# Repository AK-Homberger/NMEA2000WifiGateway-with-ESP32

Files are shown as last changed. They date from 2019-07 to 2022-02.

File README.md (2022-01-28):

# NMEA2000 Wifi Gateway with ESP32
This repository shows how to build a NMEA2000 WiFi Gateway with AIS multiplexing and voltage/temperature alarms.
The ESP32 in this project is an ESP32 NODE MCU from AzDelivery. Pin layout for other ESP32 devices might differ.

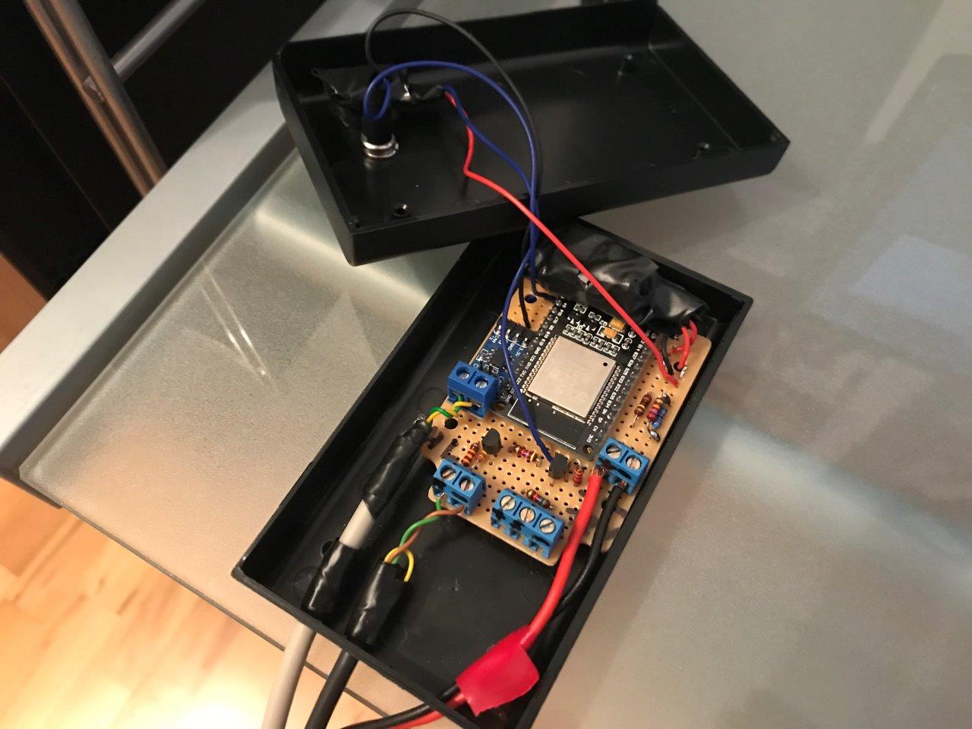
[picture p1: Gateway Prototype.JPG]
Prototype


The Gateway supports the following functions:

- Providing a WiFi Access Point for other systems like tablets or computer (e.g. with OpenCPN).
- Alternatively it can also connect as client to a WLAN network (set WLAN_CLIENT to 1 to enable).
- Forwarding navigation information from NMEA2000 to NMEA0183 as TCP stream (including log, water temp, and rudder information).
- Calculating TWS/TWD from apparent wind information and heading/COG). This allows use of OpenCPN WindHistory Dashbord instument.
- Forwarding serial NMEA0183 AIS information (on RX2) as UDP broadcast stream (for Navionics on tablets, but also for OpenCPN).
- Mutiplexing AIS information into TCP streams (to support applications that can handle only one (TCP) connection.
- Sending battery voltage and fridge temperature as NMEA2000 sentence (engine dynamic parameter PGN, my eS75 Ramarine MFD shows this as cooling temperature and alternator voltage).
- Battery voltage is measured with the ESP32 ADC.
- Fridge temperature with a Dallas DS18B20 OneWire sensor (easily extendable with more sensors).
- True parallel processing: Reading OneWire sensor as isolated task on second core of ESP32 (sensor reading is blocking for about 750 ms).
- Checking voltage and temperature levels against predefined values and generating an alarm with a piezo alarm buzzer.
- Acknowledgement of alarm with a button.
- Showing fridge temperature in web browser (nice JavaScript gauge).
- JSON interface on port 90 to request NMEA2000 data via JSON request (see M5Stack Display repository for example on usage).

The code is based on the NMEA 2000 / NMEA0183 libraries from Timo Lappalainen (https://github.com/ttlappalainen).
Download and install the libraries from GitHub link above:

- NMEA2000
- NMEA2000_esp32
- NMEA0183

The Gateway is using the following additional libraries (to be installed with the Arduiono IDE Library Manager):

- OneWire
- OneButton
- DallasTemperature
- ArduinoJson (Please use current version 6.x.x from now on)

For the ESP32 CAN bus, I used the "Waveshare SN65HVD230 Can Board" as transceiver. It works well with the ESP32.
For the Gateway, I use the pins GPIO4 for CAN RX and GPIO5 for CAN TX. The standard configuration of the NMEA2000 library would block the Serial2 connection used for AIS.

# !!!Caution!!! 
The former versions used Pin2 for TX. But I noticed problems with the NMEA2000 bus during reboot/programming of the ESP32. It looks like pin 2 is used during reboot and also during programming. A reboot confused the wind instrument (no TWS). With this new configuration evrything works without problems.

The 12 Volt is reduced to 5 Volt with a DC Step-Down_Converter (D24V10F5, https://www.pololu.com/product/2831).

The ADC of the ESP32 is a bit difficult to handle. You have to set the calibration information in the code according to the real values of the resistors at the ADC input of the ESP 32 (e.g. 15 for 100K / 27K which gives a range from 0 to 15 Volt).

# Configuration
To adjust the program to your need please change the following values in the code:

```
#define ENABLE_DEBUG_LOG 0 // Debug log, set to 1 to enable AIS forward on USB-Serial / 2 for ADC voltage to support calibration
#define UDP_Forwarding 0   // Set to 1 for forwarding AIS from serial2 to UDP brodcast
#define HighTempAlarm 12   // Alarm level for fridge temperature (higher)
#define LowVoltageAlarm 11 // Alarm level for battery voltage (lower)

#define ADC_Calibration_Value 34.3 // The real value depends on the true resistor values for the ADC input (100K / 27 K)

#define WLAN_CLIENT 0  // Set to 1 to enable client network. 0 to act as AP only

// Wifi cofiguration Client and Access Point
const char *AP_ssid = "MyESP32";  // ESP32 as AP
const char *CL_ssid = "MyWLAN";   // ESP32 as client in network

const char *AP_password = "appassword";   // AP password. Must be longer than 7 characters
const char *CL_password = "clientpassword";  // Client password

// Put IP address details here
IPAddress AP_local_ip(192, 168, 15, 1);  // Static address for AP
IPAddress AP_gateway(192, 168, 15, 1);
IPAddress AP_subnet(255, 255, 255, 0);

IPAddress CL_local_ip(192, 168, 1, 10);  // Static address for Client Network. Please adjust to your AP IP and DHCP range!
IPAddress CL_gateway(192, 168, 1, 1);
IPAddress CL_subnet(255, 255, 255, 0);
```

Schematics and PCB details are in the KiCAD folder (to allow modifications). The board can also be ordered at Aisler.net: https://aisler.net/p/DNXXRLFU

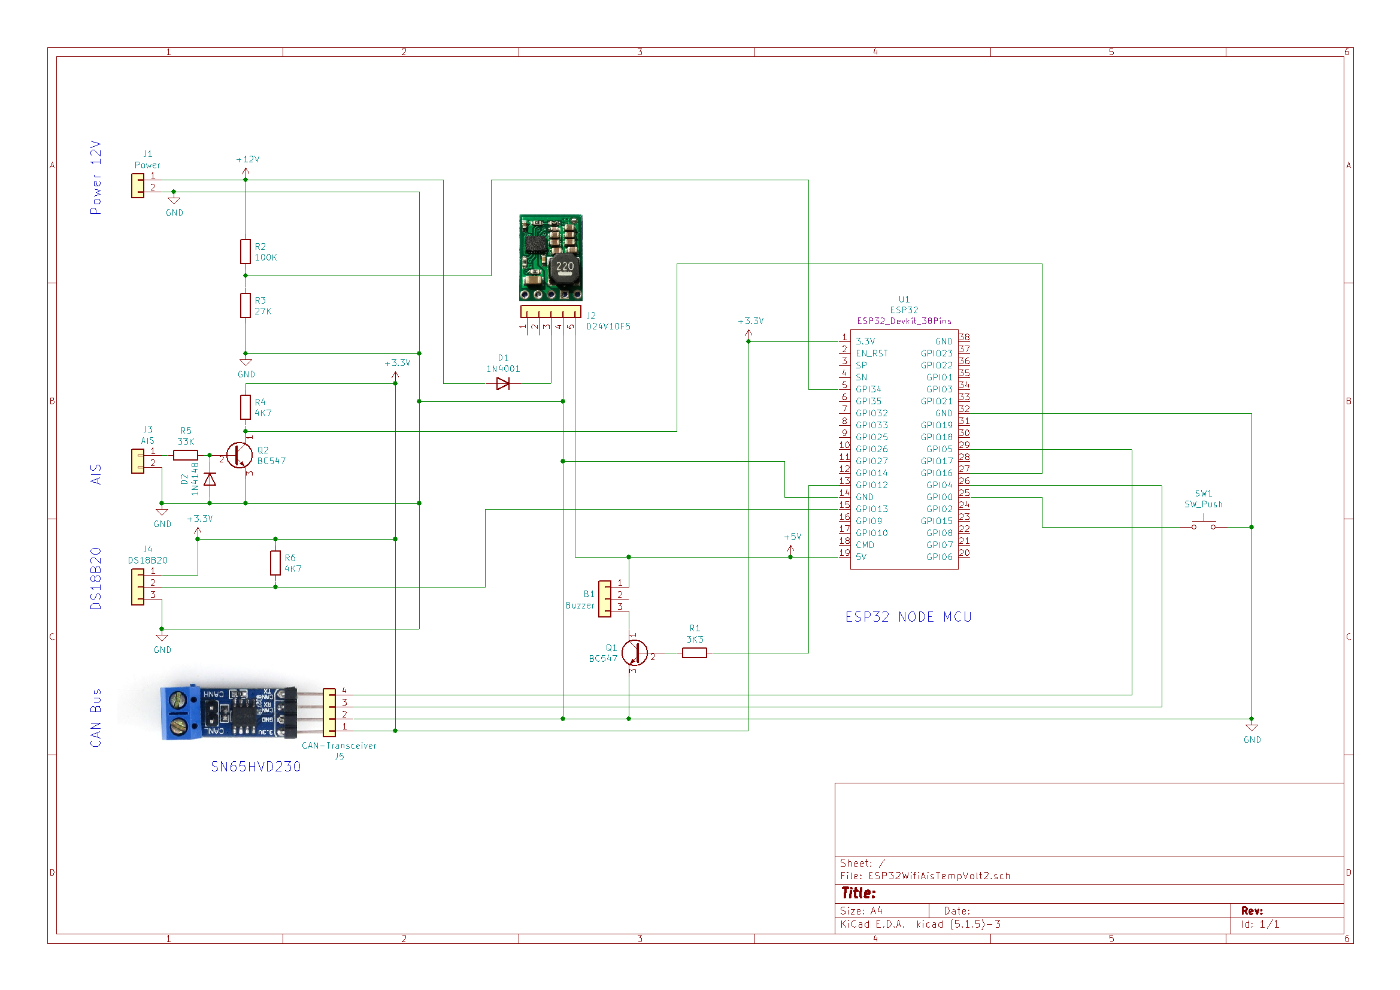
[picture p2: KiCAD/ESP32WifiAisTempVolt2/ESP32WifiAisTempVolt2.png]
Schematics


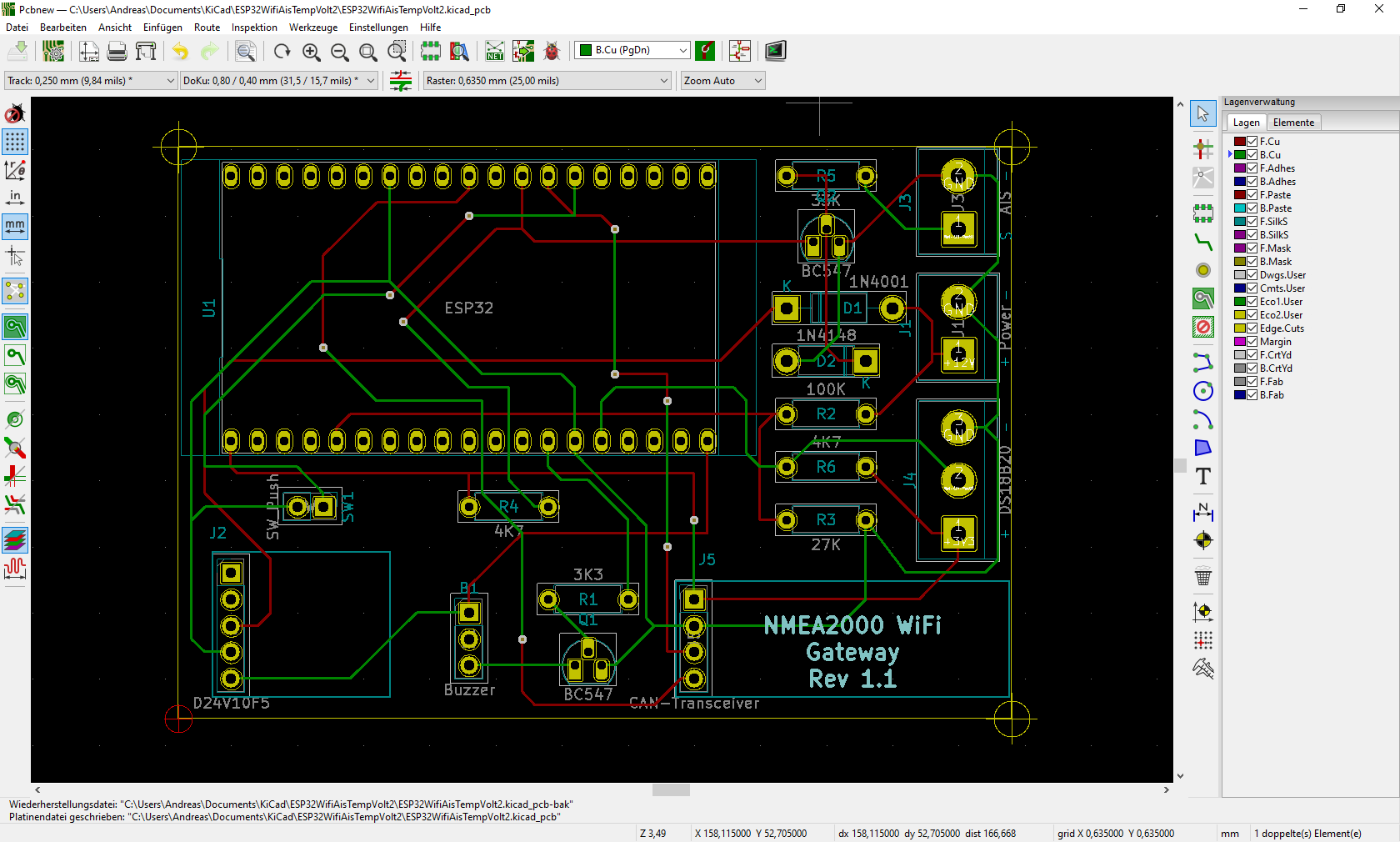
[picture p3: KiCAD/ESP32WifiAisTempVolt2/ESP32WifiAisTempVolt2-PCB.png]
PCB


# Be careful with placing the the ESP32 on the PCB. The USB connector has to be on the right side.

Fridge temperature is also shown with a nice web gauge:

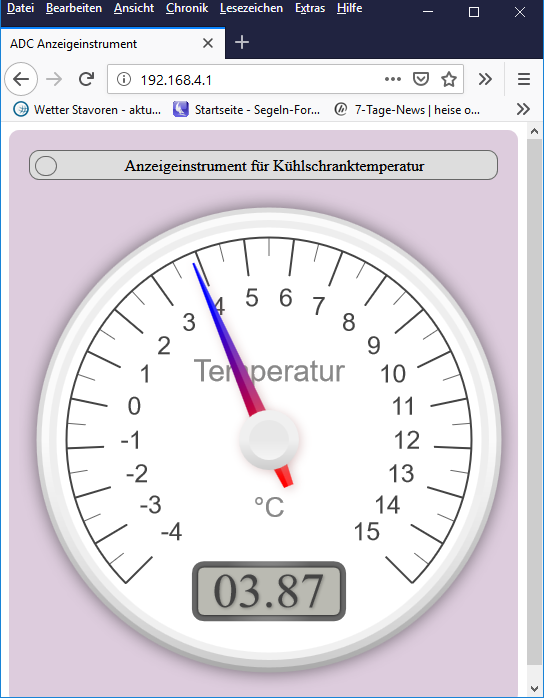
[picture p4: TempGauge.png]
TempGauge


# Remove the 120 ohm resistor from the transceiver
For unknown reasons, many CAN bus transceivers for the ESP32 have a 120 Ohm resistor built into them. The resistor does not belong to the devices at the ends of the stub lines, but to the ends of the backbone cable.

Whether the transceiver contains a 120 ohm resistor can be determined either by looking at the [circuit diagram](https://github.com/AK-Homberger/NMEA2000-Workshop/blob/main/Docs/SN65HVD230%20CAN%20Board_SCH.pdf) or by measuring with the multimeter.

A knife tip is suitable for removing the SMD resistor. Use it to scratch or pry off the resistance. With the transceiver shown here, place the tip of the knife in front of the resistor (between the chip and the resistor) and support the knife against the chip. Then lever the tip against the resistance and use it to scratch / loosen / break the resistance. Whichever happens first.

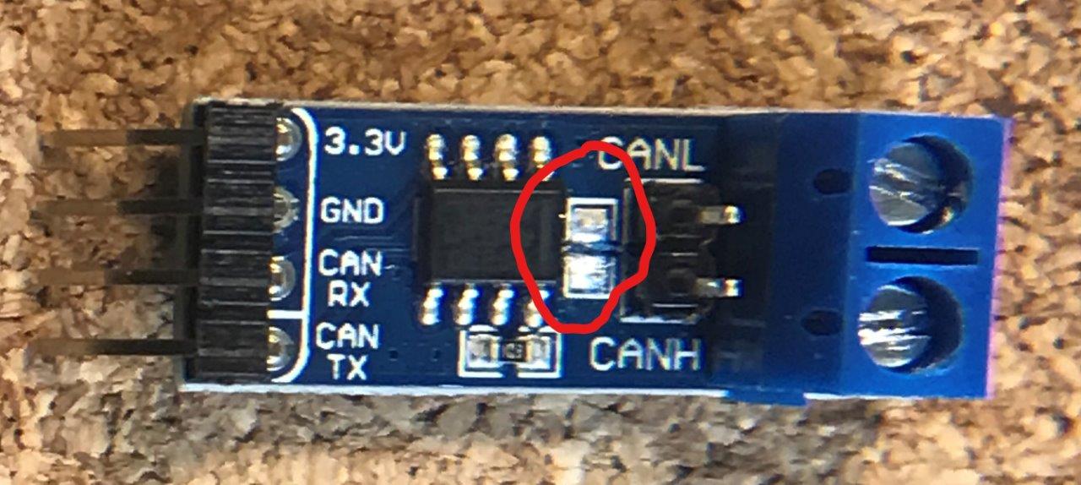
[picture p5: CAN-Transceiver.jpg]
Transceiver


It then looks like the picture. Then measure to be on the safe side. Without a 120 ohm resistor, the multimeter shows approx. 75 kOhm.

# Parts:

- Board [Link](https://aisler.net/p/DNXXRLFU)
- U1 ESP32 [Link](https://www.amazon.de/AZDelivery-NodeMCU-Development-Nachfolgermodell-ESP8266/dp/B071P98VTG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) 
- J5 SN65HVD230 [Link](https://eckstein-shop.de/WaveshareSN65HVD230CANTransceiverBoard33V2CESDProtection)
- J2 D24V10F5 [Link](https://eckstein-shop.de/Pololu5V2C1AStep-DownSpannungsreglerD24V10F5)
- B1 Buzzer [Link](https://www.reichelt.de/de/en/developer-boards-active-piezo-buzzer-module-debo-piezo-p239111.html?&nbc=1)
- R1 Resistor 3,3 KOhm [Link](https://www.reichelt.de/de/en/carbon-film-resistor-1-4-w-5-3-3-ohm-1-4w-3-3-p1396.html?&nbc=1)
- R2 Resistor 100 KOhm [Link](https://www.reichelt.de/de/en/carbon-film-resistor-1-4w-5-100-kilo-ohms-1-4w-100k-p1337.html?&nbc=1)
- R3 Resistor 27 KOhm [Link](https://www.reichelt.de/de/en/carbon-film-resistor-1-4-w-5-27-kohm-1-4w-27k-p1392.html?&nbc=1)
- R4, R6 Resistor 4,7 KOhm [Link](https://www.reichelt.de/de/en/carbon-film-resistor-1-4-w-5-4-7-kohm-1-4w-4-7k-p1425.html?&nbc=1)
- R5 Resistor 33 KOhm [Link](https://www.reichelt.de/de/en/carbon-film-resistor-1-4-w-5-33-kohm-1-4w-33k-p1412.html?&nbc=1)
- Q1, Q2 Transistor BC547 [Link](https://www.reichelt.de/de/en/small-signal-transistors-npn-to-92-45-v-rnd-bc547-p223356.html?&nbc=1)
- D1 Diode 1N4001 [Link](https://www.reichelt.com/de/en/rectifier-diode-do41-50-v-1-a-1n-4001-p1723.html?&nbc=1)
- D2 Diode 1N4148 [Link](https://www.reichelt.de/schalt-diode-100-v-150-ma-do-35-1n-4148-p1730.html?search=1n4148)
- SW1 Push button [Link](https://www.reichelt.de/miniatur-drucktaster-0-5a-24vac-1x-ein-rt-t-250a-rt-p31772.html?&trstct=pol_12&nbc=1)
- DS18B20 [Link](https://www.reichelt.com/shelly-temperatur-sensor-ds18b20-shelly-ds18b20-p287127.html?&trstct=pos_1&nbc=1)
- J4 Connector 3-pin [Link](https://www.reichelt.de/de/en/3-pin-terminal-strip-spacing-5-08-akl-101-03-p36606.html?&nbc=1)
- J1, J3 Connector 2-pin [Link](https://www.reichelt.de/de/en/2-pin-terminal-strip-spacing-5-08-akl-101-02-p36605.html?&nbc=1)
- Housing [Link](https://www.reichelt.de/de/en/plastic-housing-series-1591-57-x-87-x-36-mm-black-1591xxlsbk-p221267.html?&nbc=1)

# Updates:
- 06.11.20: Version 1.3: Changed PCB layout to version 1.1. Larger terminal blocks and different transistor footprints for easy soldering.
- 01.11.20: Version 1.3: Added KiCAD files.
- 04.08.20: Version 1.3: Changed CAN_TX to 5. Added WLAN client mode. Store last Node Address.
- 24.07.20: Version 1.2: Fixed AP setting problem (sometimes 192.168.4.1 was set after reboot).
- 23.07.20: Version 1.1: Moved to new JSON library version 6.x.x.
- 23.07.20: Version 1.0: Changed task 0 priority to 0 (see Issues) and corrected TWA calculation.
- 11.12.19: Version 0.9: Added CAN pin definition in code. No need to change settings in include file of library.
- 17.10.19: Version 0.8. Increase JSON buffer improved ID calculation.
- 14.10.19: Version 0.7. Added JSON interface on port 90. Added unique ID.
- 16.09.19: Added GGA sentence in N2kDataToNMEA0183.cpp
- 03.08.19: Version 0.4. Added rudder, log information. Calculate TWS/TWD from apparent wind, heading and COG. Added web gauge for fridge temperature (web browser, port 80).
- 23.07.19: Version 0.2 fixes the full AIS message forwarding issue. I'm now using the GetMessage function from the MNEA0183 library.

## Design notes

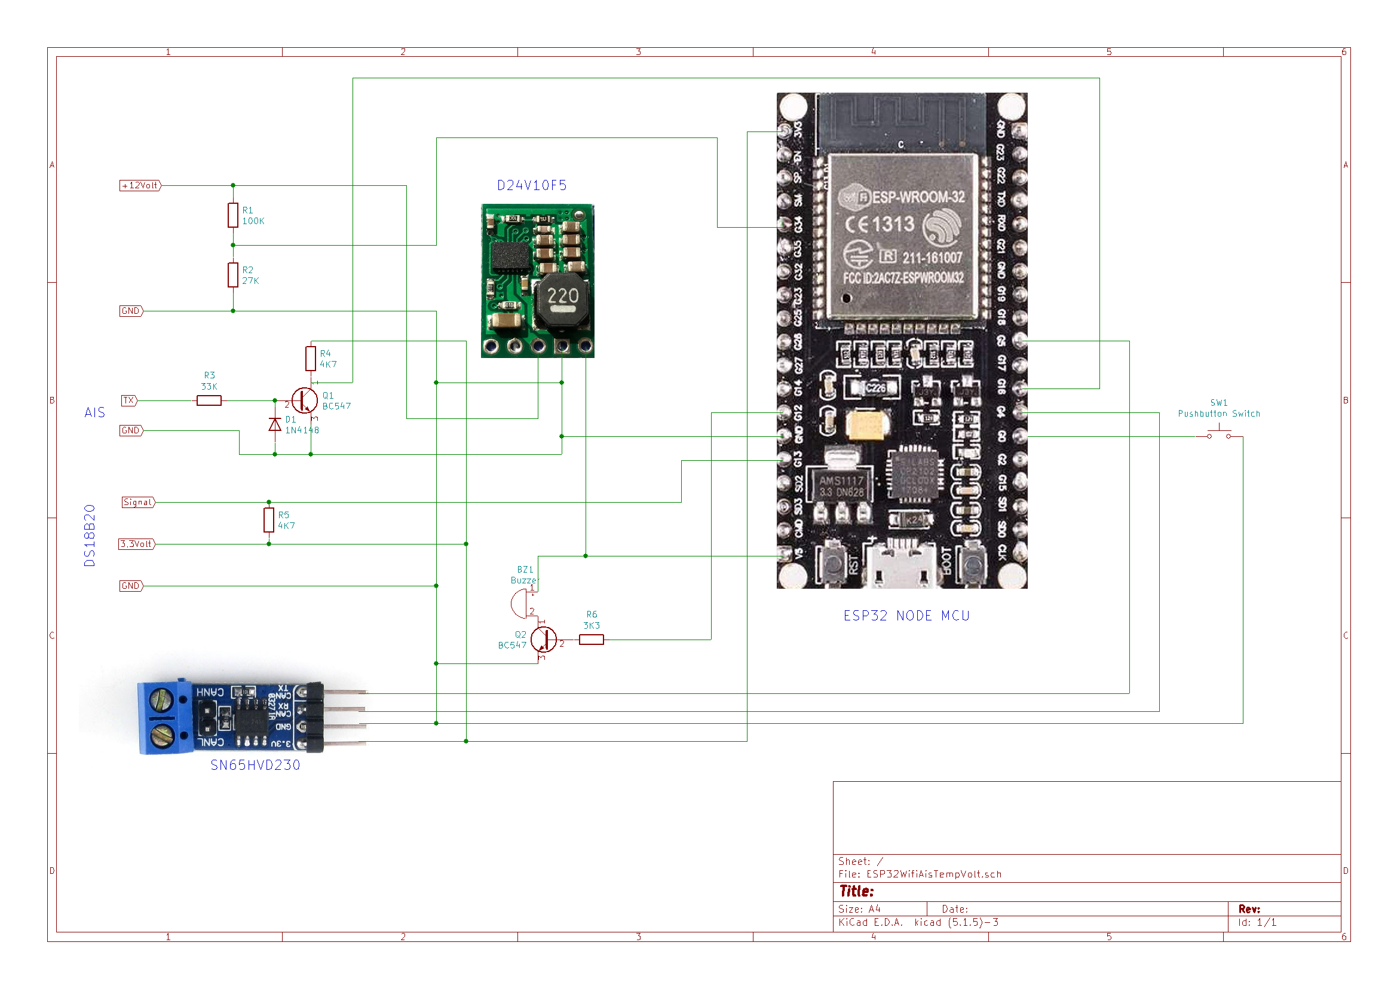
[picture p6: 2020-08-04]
NMEA 2000 WiFiGateway.png

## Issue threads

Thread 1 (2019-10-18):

ESP32_CAN Pins

ronzeiller, 2019-10-18:
Hi Andreas,
you are writing at https://github.com/ttlappalainen/NMEA2000/issues/97#issuecomment-513720750 that

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

But I could not find those pin definitions in your code?

Thanks,
Ronnie

AK-Homberger, 2019-10-31:
Hi Ronnie,

You are right. I changed the settinge in header file for the ESP 32 NMEA2000 library "NMEA2000_esp32.h":

#ifndef ESP32_CAN_TX_PIN
#define ESP32_CAN_TX_PIN GPIO_NUM_2
#endif
#ifndef ESP32_CAN_RX_PIN
#define ESP32_CAN_RX_PIN GPIO_NUM_4
#endif

It would be probably better to define it direcrtly in the main code to avoid confusion.

Regards,
Andreas

Closed 2019-12-11.

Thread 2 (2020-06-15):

Problems ArduinoJson

usauerbrey, 2020-06-15:
Hi
I have problems when trying to compile you NMEA-Gateway.

Wifi-Serial-AP-AIS-CAN.ino: 413:11: error: StaticJsonBuffer is a class from ArduinoJson 5. Please see arduinojson.org\upgrade to learn how to upgrade your program to ArduinoJson version 6
   StaticJsonBuffer<800> jsonBuffer

Any solution/recommendation?

Best Regards Uwe

AndrasSzep, 2020-06-15:
Hi Uwe,

Actually I only forked the library from
AK-Homberger/NMEA2000WifiGateway-with-ESP32 and used only to develop
my own apps.
If you describe what you want perhaps I can give you some hints.

Kind regards,

------------------
András Szép
andras.szep@gmail.com
UK: +44 - 7824 35 9474

------------------
András Szép
andras.szep@gmail.com
UK: +44 - 7824 35 9474

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

AK-Homberger, 2020-06-15:
Did you install the JSON library version 5?

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

AndrasSzep, 2020-06-15:
I have ArduinoJSON 6.15.2 installed on my comp, but not sure if I ever used
It yet.
I have an app publishing NMEA2000 messages in NMEA0183 format as a TCP
stream. This can be used by OpenCPN.
Also just made the other way around - translating NMEA0183 messages from a
TCP stream into NMEA2000 bus.

------------------
András Szép
andras.szep@gmail.com
UK: +44 - 7824 35 9474

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

usauerbrey, 2020-06-15:
I was able to install ArduinoJSON 5 instead of ArduinoJSON 6. I was not aware, that this is posslible.
So now it woks, even so it is not perfect, not using the latest libriries.

AK-Homberger, 2020-06-15:
You have to use JSON version 5 not 6. Then it should work.

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

AK-Homberger, 2020-07-24:
Now the code works with ArduinoJSON verion 6.

Closed 2020-06-16.

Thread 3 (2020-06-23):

Compiling on PlatformIO

AAKFISHERMANN, 2020-06-23:
HI, i tried to compile this code on Atom PlatformIO. Using different espressif32 platform versions (1.7.0, 1.8.0 and the last 1.12.4) i have the same error at the end of compiling;

Linking .pio\build\esp32doit-devkit-v1\firmware.elf
.pio\build\esp32doit-devkit-v1\src\main.cpp.o:(.literal.startup._GLOBAL__sub_I_NMEA2000+0x10): **undefined reference to `vtable for tN2kDataToNMEA0183'**
.pio\build\esp32doit-devkit-v1\src\main.cpp.o:(.literal._Z4loopv+0x4): **undefined reference to `tN2kDataToNMEA0183::Update(tBoatData*)'**
.pio\build\esp32doit-devkit-v1\src\main.cpp.o: In function `loop()':
main.cpp:(.text._Z4loopv+0x39): **undefined reference to `tN2kDataToNMEA0183::Update(tBoatData*)'**
collect2.exe: error: ld returned 1 exit status
*** [.pio\build\esp32doit-devkit-v1\firmware.elf] Error 1

Is there some kind a problem in one library?
Thanks

AK-Homberger, 2020-06-23:
Hi,
I don’t use this environment. Regarding problems with the libraries you should check this with the author of the libraries, Timo Lappalainen.

Regards
Andreas

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

AndrasSzep, 2020-06-23:
Sometimes it is quite funny the behavior of the different ESP32 chips.
Errors when loading the programs maybe caused by too much current load or
too long USB cables. Some chips need lower loading speeds and or pushing
the boot button...

On Tue, 23 Jun 2020 at 19:57, AAKFISHERMANN <notifications@github.com>
wrote:

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
--
András

AK-Homberger, 2020-07-23:
PlatformIO is not supported.

Closed 2020-07-23.

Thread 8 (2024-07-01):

infinite loop when wifi client disconnects

florent1080, 2024-07-01:
When a wifi client is disconnected, the SendBufToClients() timeout is too long and the code loops infinitely in HandleNMEA2000Msg(), because messages are arriving on the Can bus. I don't have a fix yet, but I'm working on it.

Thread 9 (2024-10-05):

NMEA2000_esp does not compile.

dfs-brent, 2024-10-05:
I had to comment out the following lines from the NMEA2000_esp.cpp to get it to compile:
        Line 124:   ///periph_module_reset(PERIPH_CAN_MODULE);
	Line 128:   ///DPORT_SET_PERI_REG_MASK(DPORT_PERIP_CLK_EN_REG, DPORT_CAN_CLK_EN);
	Line 129:   ///DPORT_CLEAR_PERI_REG_MASK(DPORT_PERIP_RST_EN_REG, DPORT_CAN_RST);
	Line 194:     ///esp_intr_alloc(ETS_CAN_INTR_SOURCE,0,ESP32Can1Interrupt,NULL,NULL);

It does not know what the *_CAN_* macros are.  Obviously, it will not work without these lines.  Any idea how to fix this properly?

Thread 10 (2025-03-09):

ESP32_ DS18B20

Machansen, 2025-03-09:
Hello,

I would like to read the DS18B20. Unfortunately, the sensors don't seem to be recognized. The signal is connected to pin 13 and tested. Do the sensors need to be installed separately? They are also not shown under 'Show Unmapped'.

Thank you for your help!

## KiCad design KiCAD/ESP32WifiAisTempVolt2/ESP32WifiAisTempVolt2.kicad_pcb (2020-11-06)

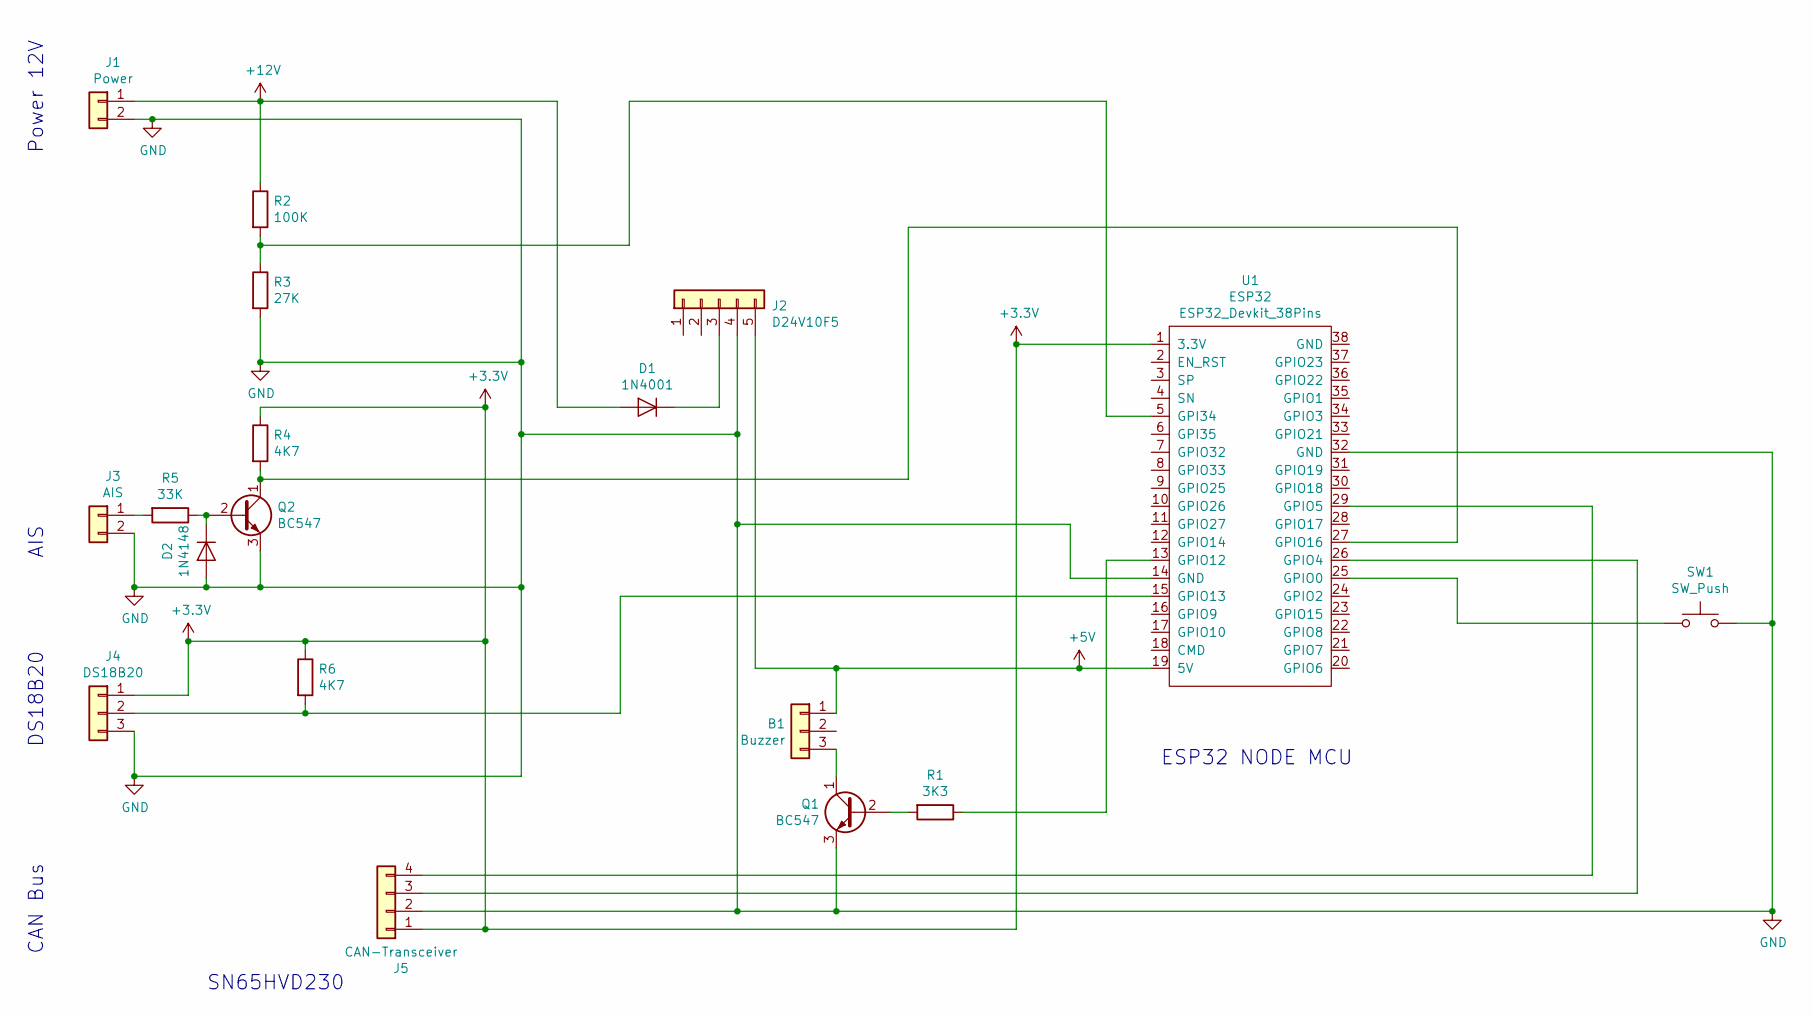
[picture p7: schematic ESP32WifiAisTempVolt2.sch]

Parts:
B1: Buzzer; PinHeader_1x03_P2.54mm_Vertical
D1: 1N4001; D_DO-41_SOD81_P10.16mm_Horizontal
D2: 1N4148; D_DO-41_SOD81_P7.62mm_Horizontal
J1: Power; TerminalBlock_bornier-2_P5.08mm
J2: D24V10F5; PinHeader_1x05_P2.54mm_Vertical
J3: AIS; TerminalBlock_bornier-2_P5.08mm
J4: DS18B20; TerminalBlock_bornier-3_P5.08mm
J5: CAN-Transceiver; PinHeader_1x04_P2.54mm_Vertical
Q1, Q2: BC547; TO-92_HandSolder
R1: 3K3; R_Axial_DIN0207_L6.3mm_D2.5mm_P7.62mm_Horizontal
R2: 100K; R_Axial_DIN0207_L6.3mm_D2.5mm_P7.62mm_Horizontal
R3: 27K; R_Axial_DIN0207_L6.3mm_D2.5mm_P7.62mm_Horizontal
R4, R6: 4K7; R_Axial_DIN0207_L6.3mm_D2.5mm_P7.62mm_Horizontal
R5: 33K; R_Axial_DIN0207_L6.3mm_D2.5mm_P7.62mm_Horizontal
SW1: SW_Push; PinHeader_1x02_P2.54mm_Vertical
U1: ESP32; ESP32_Devkit_38Pins

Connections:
+3V3: J4.1, J5.1, R4.1, R6.1, U1.1 (3.3V)
+5V: B1.1, J2.5, U1.19 (5V)
+12V: D1.2 (A), J1.1, R2.1
GND: D2.2 (A), J1.2, J2.4, J3.2, J4.3, J5.2, Q1.3 (E), Q2.3 (E), R3.2, SW1.2, U1.14 (GND), U1.32 (GND)
unnamed: B1.3, Q1.1 (C)
unnamed: D1.1 (K), J2.3
unnamed: D2.1 (K), Q2.2 (B), R5.1
unnamed: J3.1, R5.2
unnamed: J4.2, R6.2, U1.15 (GPIO13)
unnamed: J5.3, U1.26 (GPIO4)
unnamed: J5.4, U1.29 (GPIO5)
unnamed: Q1.2 (B), R1.2
unnamed: Q2.1 (C), R4.2, U1.27 (GPIO16)
unnamed: R1.1, U1.13 (GPIO12)
unnamed: R2.2, R3.1, U1.5 (GPI34)
unnamed: SW1.1, U1.25 (GPIO0)

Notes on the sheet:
ESP32 NODE MCU
SN65HVD230
CAN Bus
Power 12V
DS18B20
AIS

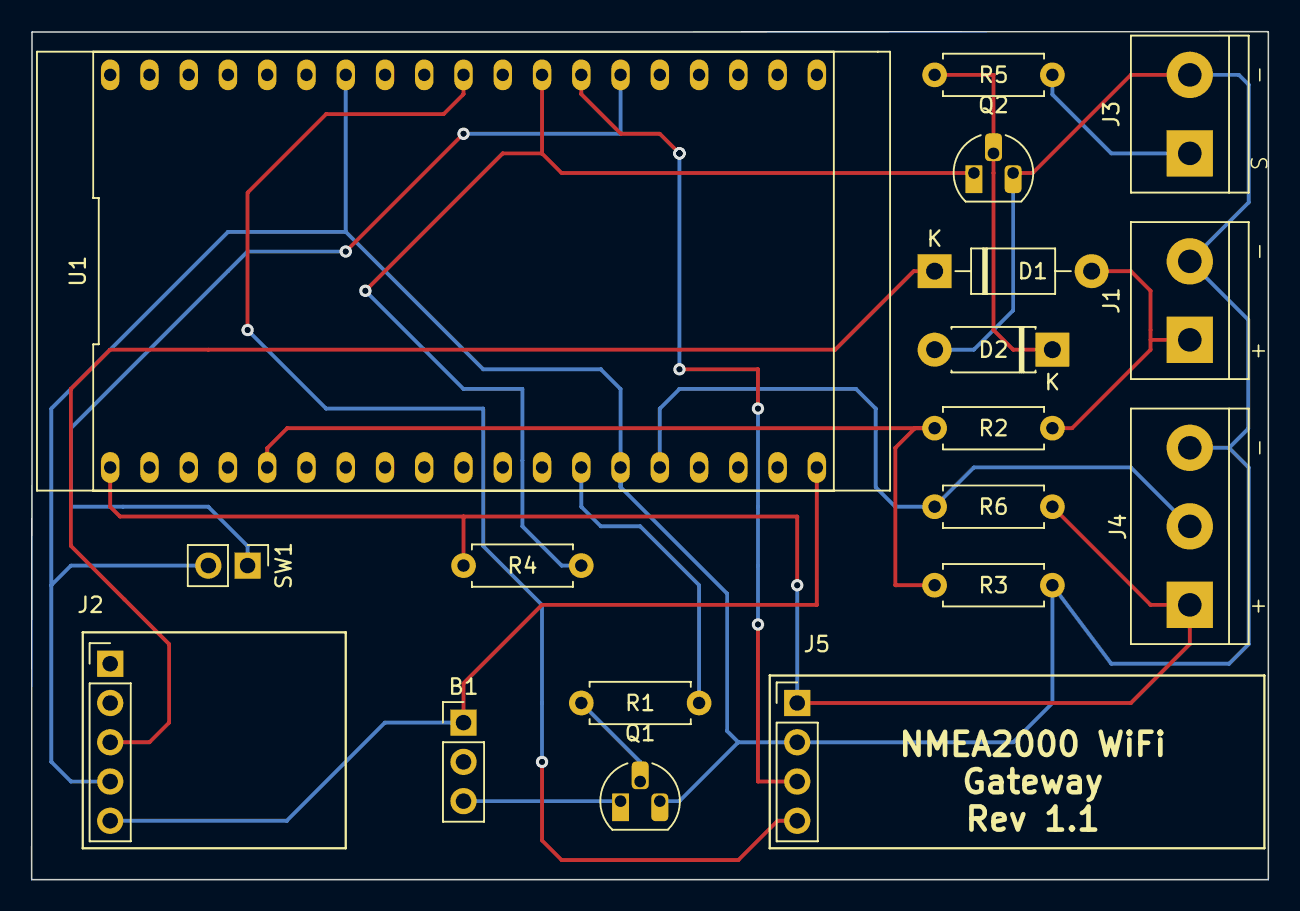
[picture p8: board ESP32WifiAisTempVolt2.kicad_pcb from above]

Board: 2 copper layers, 80.0 x 54.9 mm, 18 parts (0 on the bottom side), 16 nets.

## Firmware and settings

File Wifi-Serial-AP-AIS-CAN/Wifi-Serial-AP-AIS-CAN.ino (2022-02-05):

/*
  This code is free software; you can redistribute it and/or
  modify it under the terms of the GNU Lesser General Public
  License as published by the Free Software Foundation; either
  version 2.1 of the License, or (at your option) any later version.
  This code is distributed in the hope that it will be useful,
  but WITHOUT ANY WARRANTY; without even the implied warranty of
  MERCHANTABILITY or FITNESS FOR A PARTICULAR PURPOSE.  See the GNU
  Lesser General Public License for more details.
  You should have received a copy of the GNU Lesser General Public
  License along with this library; if not, write to the Free Software
  Foundation, Inc., 51 Franklin St, Fifth Floor, Boston, MA  02110-1301  USA
*/

// Version 1.3, 04.08.2020, AK-Homberger

#define ESP32_CAN_TX_PIN GPIO_NUM_5  // Set CAN TX port to 5 (Caution!!! Pin 2 before)
#define ESP32_CAN_RX_PIN GPIO_NUM_4  // Set CAN RX port to 4

#include <Arduino.h>
#include <NMEA2000_CAN.h>  // This will automatically choose right CAN library and create suitable NMEA2000 object
#include <Seasmart.h>
#include <N2kMessages.h>
#include <WiFi.h>
#include <WebServer.h>
#include <OneWire.h>
#include <OneButton.h>
#include <DallasTemperature.h>
#include <Preferences.h>
#include <ArduinoJson.h>

#include "N2kDataToNMEA0183.h"
#include "List.h"
#include "index_html.h"
#include "BoatData.h"


#define ENABLE_DEBUG_LOG 0 // Debug log, set to 1 to enable AIS forward on USB-Serial / 2 for ADC voltage to support calibration
#define UDP_Forwarding 0   // Set to 1 for forwarding AIS from serial2 to UDP brodcast
#define HighTempAlarm 12   // Alarm level for fridge temperature (higher)
#define LowVoltageAlarm 11 // Alarm level for battery voltage (lower)

#define ADC_Calibration_Value 34.3 // The real value depends on the true resistor values for the ADC input (100K / 27 K)

#define WLAN_CLIENT 0  // Set to 1 to enable client network. 0 to act as AP only

// Wifi cofiguration Client and Access Point
const char *AP_ssid = "MyESP32";  // ESP32 as AP
const char *CL_ssid = "MyWLAN";   // ESP32 as client in network

const char *AP_password = "appassword";   // AP password. Must be longer than 7 characters
const char *CL_password = "clientpassword";  // Client password

// Put IP address details here
IPAddress AP_local_ip(192, 168, 15, 1);  // Static address for AP
IPAddress AP_gateway(192, 168, 15, 1);
IPAddress AP_subnet(255, 255, 255, 0);

IPAddress CL_local_ip(192, 168, 1, 10);  // Static address for Client Network. Please adjust to your AP IP and DHCP range!
IPAddress CL_gateway(192, 168, 1, 1);
IPAddress CL_subnet(255, 255, 255, 0);

int wifiType = 0; // 0= Client 1= AP

const uint16_t ServerPort = 2222; // Define the port, where server sends data. Use this e.g. on OpenCPN. Use 39150 for Navionis AIS

// UPD broadcast for Navionics, OpenCPN, etc.
const char * udpAddress = "192.168.15.255"; // UDP broadcast address. Should be the network of the ESP32 AP (please check!)
const int udpPort = 2000; // port 2000 lets think Navionics it is an DY WLN10 device

// Create UDP instance
WiFiUDP udp;

// Struct to update BoatData. See BoatData.h for content
tBoatData BoatData;

int NodeAddress;  // To store last Node Address

Preferences preferences;             // Nonvolatile storage on ESP32 - To store LastDeviceAddress

int buzzerPin = 12;   // Buzzer on GPIO 12
int buttonPin = 0;    // Button on GPIO 0 to acknowledge alarm with buzzer
int alarmstate = false; // Alarm state (low voltage/temperature)
int acknowledge = false; // Acknowledge for alarm, button pressed

OneButton button(buttonPin, false); // The OneButton library is used to debounce the acknowledge button

const size_t MaxClients = 10;
bool SendNMEA0183Conversion = true; // Do we send NMEA2000 -> NMEA0183 conversion
bool SendSeaSmart = false; // Do we send NMEA2000 messages in SeaSmart format

WiFiServer server(ServerPort, MaxClients);
WiFiServer json(90);

using tWiFiClientPtr = std::shared_ptr<WiFiClient>;
LinkedList<tWiFiClientPtr> clients;

tN2kDataToNMEA0183 tN2kDataToNMEA0183(&NMEA2000, 0);

// Set the information for other bus devices, which messages we support
const unsigned long TransmitMessages[] PROGMEM = {127489L, // Engine dynamic
                                                  0
                                                 };
const unsigned long ReceiveMessages[] PROGMEM = {/*126992L,*/ // System time
      127250L, // Heading
      127258L, // Magnetic variation
      128259UL,// Boat speed
      128267UL,// Depth
      129025UL,// Position
      129026L, // COG and SOG
      129029L, // GNSS
      130306L, // Wind
      128275UL,// Log
      127245UL,// Rudder
      0
    };

// Forward declarations
void HandleNMEA2000Msg(const tN2kMsg &N2kMsg);
void SendNMEA0183Message(const tNMEA0183Msg &NMEA0183Msg);

// Data wire for teperature (Dallas DS18B20) is plugged into GPIO 13 on the ESP32
#define ONE_WIRE_BUS 13
// Setup a oneWire instance to communicate with any OneWire devices (not just Maxim/Dallas temperature ICs)
OneWire oneWire(ONE_WIRE_BUS);
// Pass our oneWire reference to Dallas Temperature.
DallasTemperature sensors(&oneWire);

WebServer webserver(80);

#define MiscSendOffset 120
#define SlowDataUpdatePeriod 1000  // Time between CAN Messages sent

// Battery voltage is connected GPIO 34 (Analog ADC1_CH6)
const int ADCpin = 34;
float voltage = 0;
float temp = 0;

// Task handle for OneWire read (Core 0 on ESP32)
TaskHandle_t Task1;

// Serial port 2 config (GPIO 16)
const int baudrate = 38400;
const int rs_config = SERIAL_8N1;

// Buffer config

#define MAX_NMEA0183_MESSAGE_SIZE 150 // For AIS
char buff[MAX_NMEA0183_MESSAGE_SIZE];

// NMEA message for AIS receiving and multiplexing
tNMEA0183Msg NMEA0183Msg;
tNMEA0183 NMEA0183;


void debug_log(char* str) {
#if ENABLE_DEBUG_LOG == 1
  Serial.println(str);
#endif
}



void setup() {

  uint8_t chipid[6];
  uint32_t id = 0;
  int i = 0;
  int wifi_retry = 0;

  pinMode(buzzerPin, OUTPUT);
  pinMode(buttonPin, INPUT_PULLUP);

  button.attachClick(clickedIt);

  // Init USB serial port
  Serial.begin(115200);

  // Init AIS serial port 2
  Serial2.begin(baudrate, rs_config);
  NMEA0183.Begin(&Serial2, 3, baudrate);

  if (WLAN_CLIENT == 1) {
    Serial.println("Start WLAN Client");         // WiFi Mode Client

    WiFi.config(CL_local_ip, CL_gateway, CL_subnet, CL_gateway);
    delay(100);
    WiFi.begin(CL_ssid, CL_password);

    while (WiFi.status() != WL_CONNECTED  && wifi_retry < 20) {         // Check connection, try 10 seconds
      wifi_retry++;
      delay(500);
      Serial.print(".");
    }
  }

  if (WiFi.status() != WL_CONNECTED) {   // No client connection start AP
    // Init wifi connection
    Serial.println("Start WLAN AP");         // WiFi Mode AP
    WiFi.mode(WIFI_AP);
    WiFi.softAP(AP_ssid, AP_password);
    delay(100);
    WiFi.softAPConfig(AP_local_ip, AP_gateway, AP_subnet);
    IPAddress IP = WiFi.softAPIP();
    Serial.println("");
    Serial.print("AP IP address: ");
    Serial.println(IP);
    wifiType = 1;

  } else {  // Wifi Client connection was sucessfull

    Serial.println("");
    Serial.println("WiFi client connected");
    Serial.println("IP client address: ");
    Serial.println(WiFi.localIP());
  }

  // Start OneWire
  sensors.begin();

  // Start TCP server
  server.begin();

  // Start JSON server
  json.begin();


  // Start Web Server
  webserver.on("/", Ereignis_Index);
  webserver.on("/gauge.min.js", Ereignis_js);
  webserver.on("/ADC.txt", Ereignis_ADC);
  webserver.onNotFound(handleNotFound);

  webserver.begin();
  Serial.println("HTTP server started");

  // Reserve enough buffer for sending all messages. This does not work on small memory devices like Uno or Mega

  NMEA2000.SetN2kCANMsgBufSize(8);
  NMEA2000.SetN2kCANReceiveFrameBufSize(250);
  NMEA2000.SetN2kCANSendFrameBufSize(250);

  esp_efuse_mac_get_default(chipid);
  for (i = 0; i < 6; i++) id += (chipid[i] << (7 * i));

  // Set product information
  NMEA2000.SetProductInformation("1", // Manufacturer's Model serial code
                                 100, // Manufacturer's product code
                                 "NMEA 2000 WiFi Gateway",  // Manufacturer's Model ID
                                 "1.0.2.25 (2019-07-07)",  // Manufacturer's Software version code
                                 "1.0.2.0 (2019-07-07)" // Manufacturer's Model version
                                );
  // Set device information
  NMEA2000.SetDeviceInformation(id, // Unique number. Use e.g. Serial number. Id is generated from MAC-Address
                                130, // Device function=Analog to NMEA 2000 Gateway. See codes on http://www.nmea.org/Assets/20120726%20nmea%202000%20class%20&%20function%20codes%20v%202.00.pdf
                                25, // Device class=Inter/Intranetwork Device. See codes on  http://www.nmea.org/Assets/20120726%20nmea%202000%20class%20&%20function%20codes%20v%202.00.pdf
                                2046 // Just choosen free from code list on http://www.nmea.org/Assets/20121020%20nmea%202000%20registration%20list.pdf
                               );

  // If you also want to see all traffic on the bus use N2km_ListenAndNode instead of N2km_NodeOnly below

  NMEA2000.SetForwardType(tNMEA2000::fwdt_Text); // Show in clear text. Leave uncommented for default Actisense format.

  preferences.begin("nvs", false);                          // Open nonvolatile storage (nvs)
  NodeAddress = preferences.getInt("LastNodeAddress", 32);  // Read stored last NodeAddress, default 32
  preferences.end();

  Serial.printf("NodeAddress=%d\n", NodeAddress);

  NMEA2000.SetMode(tNMEA2000::N2km_ListenAndNode, NodeAddress);

  NMEA2000.ExtendTransmitMessages(TransmitMessages);
  NMEA2000.ExtendReceiveMessages(ReceiveMessages);
  NMEA2000.AttachMsgHandler(&tN2kDataToNMEA0183); // NMEA 2000 -> NMEA 0183 conversion
  NMEA2000.SetMsgHandler(HandleNMEA2000Msg); // Also send all NMEA2000 messages in SeaSmart format

  tN2kDataToNMEA0183.SetSendNMEA0183MessageCallback(SendNMEA0183Message);

  NMEA2000.Open();

  // Create task for core 0, loop() runs on core 1
  xTaskCreatePinnedToCore(
    GetTemperature, /* Function to implement the task */
    "Task1", /* Name of the task */
    10000,  /* Stack size in words */
    NULL,  /* Task input parameter */
    0,  /* Priority of the task */
    &Task1,  /* Task handle. */
    0); /* Core where the task should run */

  delay(200);
}

// This task runs isolated on core 0 because sensors.requestTemperatures() is slow and blocking for about 750 ms
void GetTemperature( void * parameter) {
  float tmp = 0;
  for (;;) {
    sensors.requestTemperatures(); // Send the command to get temperatures
    vTaskDelay(100);
    tmp = sensors.getTempCByIndex(0);
    if (tmp != -127) temp = tmp;
    vTaskDelay(100);
  }
}

//*****************************************************************************

void Ereignis_Index()    // Wenn "http://<ip address>/" aufgerufen wurde
{
  webserver.send(200, "text/html", indexHTML);  //dann Index Webseite senden
}

void Ereignis_js()      // Wenn "http://<ip address>/gauge.min.js" aufgerufen wurde
{
  webserver.send(200, "text/html", gauge);     // dann gauge.min.js senden
}

void Ereignis_ADC()     // Wenn "http://<ip address>/ADC.txt" aufgerufen wurde
{

  webserver.sendHeader("Cache-Control", "no-cache");  // Sehr wichtig !!!!!!!!!!!!!!!!!!!
  webserver.send(200, "text/plain", String (temp));   // dann text mit ADC Wert senden
}

void handleNotFound()
{
  webserver.send(404, "text/plain", "File Not Found\n\n");
}


//*****************************************************************************
void SendBufToClients(const char *buf) {
  for (auto it = clients.begin() ; it != clients.end(); it++) {
    if ( (*it) != NULL && (*it)->connected() ) {
      (*it)->println(buf);
    }
  }
}

#define MAX_NMEA2000_MESSAGE_SEASMART_SIZE 500
//*****************************************************************************
//NMEA 2000 message handler
void HandleNMEA2000Msg(const tN2kMsg &N2kMsg) {


  if ( !SendSeaSmart ) return;

  char buf[MAX_NMEA2000_MESSAGE_SEASMART_SIZE];
  if ( N2kToSeasmart(N2kMsg, millis(), buf, MAX_NMEA2000_MESSAGE_SEASMART_SIZE) == 0 ) return;
  SendBufToClients(buf);
}


//*****************************************************************************
void SendNMEA0183Message(const tNMEA0183Msg &NMEA0183Msg) {
  if ( !SendNMEA0183Conversion ) return;

  char buf[MAX_NMEA0183_MESSAGE_SIZE];
  if ( !NMEA0183Msg.GetMessage(buf, MAX_NMEA0183_MESSAGE_SIZE) ) return;
  SendBufToClients(buf);
}


bool IsTimeToUpdate(unsigned long NextUpdate) {
  return (NextUpdate < millis());
}
unsigned long InitNextUpdate(unsigned long Period, unsigned long Offset = 0) {
  return millis() + Period + Offset;
}

void SetNextUpdate(unsigned long &NextUpdate, unsigned long Period) {
  while ( NextUpdate < millis() ) NextUpdate += Period;
}


void SendN2kEngine() {
  static unsigned long SlowDataUpdated = InitNextUpdate(SlowDataUpdatePeriod, MiscSendOffset);
  tN2kMsg N2kMsg;

  if ( IsTimeToUpdate(SlowDataUpdated) ) {
    SetNextUpdate(SlowDataUpdated, SlowDataUpdatePeriod);

    SetN2kEngineDynamicParam(N2kMsg, 0, N2kDoubleNA, N2kDoubleNA, CToKelvin(temp), voltage, N2kDoubleNA, N2kDoubleNA, N2kDoubleNA, N2kDoubleNA, N2kInt8NA, N2kInt8NA, true);
    NMEA2000.SendMsg(N2kMsg);
  }
}


//*****************************************************************************
void AddClient(WiFiClient &client) {
  Serial.println("New Client.");
  clients.push_back(tWiFiClientPtr(new WiFiClient(client)));
}

//*****************************************************************************
void StopClient(LinkedList<tWiFiClientPtr>::iterator &it) {
  Serial.println("Client Disconnected.");
  (*it)->stop();
  it = clients.erase(it);
}

//*****************************************************************************
void CheckConnections() {
  WiFiClient client = server.available();   // listen for incoming clients

  if ( client ) AddClient(client);

  for (auto it = clients.begin(); it != clients.end(); it++) {
    if ( (*it) != NULL ) {
      if ( !(*it)->connected() ) {
        StopClient(it);
      } else {
        if ( (*it)->available() ) {
          char c = (*it)->read();
          if ( c == 0x03 ) StopClient(it); // Close connection by ctrl-c
        }
      }
    } else {
      it = clients.erase(it); // Should have been erased by StopClient
    }
  }
}

// ReadVoltage is used to improve the linearity of the ESP32 ADC see: https://github.com/G6EJD/ESP32-ADC-Accuracy-Improvement-function

double ReadVoltage(byte pin) {
  double reading = analogRead(pin); // Reference voltage is 3v3 so maximum reading is 3v3 = 4095 in range 0 to 4095
  if (reading < 1 || reading > 4095) return 0;
  // return -0.000000000009824 * pow(reading,3) + 0.000000016557283 * pow(reading,2) + 0.000854596860691 * reading + 0.065440348345433;
  return (-0.000000000000016 * pow(reading, 4) + 0.000000000118171 * pow(reading, 3) - 0.000000301211691 * pow(reading, 2) + 0.001109019271794 * reading + 0.034143524634089) * 1000;
} // Added an improved polynomial, use either, comment out as required


void clickedIt() {  // Button was pressed
  acknowledge = !acknowledge;
}



void handle_json() {

  WiFiClient client = json.available();

  // Do we have a client?
  if (!client) return;

  // Serial.println(F("New client"));

  // Read the request (we ignore the content in this example)
  while (client.available()) client.read();

  // Allocate JsonBuffer
  // Use arduinojson.org/assistant to compute the capacity.
  StaticJsonDocument<800> root;

  root["Latitude"] = BoatData.Latitude;
  root["Longitude"] = BoatData.Longitude;
  root["Heading"] = BoatData.Heading;
  root["COG"] = BoatData.COG;
  root["SOG"] = BoatData.SOG;
  root["STW"] = BoatData.STW;
  root["AWS"] = BoatData.AWS;
  root["TWS"] = BoatData.TWS;
  root["MaxAws"] = BoatData.MaxAws;
  root["MaxTws"] = BoatData.MaxTws;
  root["AWA"] = BoatData.AWA;
  root["TWA"] = BoatData.TWA;
  root["TWD"] = BoatData.TWD;
  root["TripLog"] = BoatData.TripLog;
  root["Log"] = BoatData.Log;
  root["RudderPosition"] = BoatData.RudderPosition;
  root["WaterTemperature"] = BoatData.WaterTemperature;
  root["WaterDepth"] = BoatData.WaterDepth;
  root["Variation"] = BoatData.Variation;
  root["Altitude"] = BoatData.Altitude;
  root["GPSTime"] = BoatData.GPSTime;
  root["DaysSince1970"] = BoatData.DaysSince1970;
  root["FridgeTeperature"] = temp;
  root["BatteryVoltage"] = voltage;


  //Serial.print(F("Sending: "));
  //serializeJson(root, Serial);
  //Serial.println();

  // Write response headers
  client.println("HTTP/1.0 200 OK");
  client.println("Content-Type: application/json");
  client.println("Connection: close");
  client.println();

  // Write JSON document
  serializeJsonPretty(root, client);

  // Disconnect
  client.stop();
}



void loop() {
  unsigned int size;
  int wifi_retry;

  webserver.handleClient();
  handle_json();

  if (NMEA0183.GetMessage(NMEA0183Msg)) {  // Get AIS NMEA sentences from serial2

    SendNMEA0183Message(NMEA0183Msg);      // Send to TCP clients

    NMEA0183Msg.GetMessage(buff, MAX_NMEA0183_MESSAGE_SIZE); // send to buffer

#if ENABLE_DEBUG_LOG == 1
    Serial.println(buff);
#endif

#if UDP_Forwarding == 1
    size = strlen(buff);
    udp.beginPacket(udpAddress, udpPort);  // Send to UDP
    udp.write((byte*)buff, size);
    udp.endPacket();
#endif
  }

  voltage = ((voltage * 15) + (ReadVoltage(ADCpin) * ADC_Calibration_Value / 4096)) / 16; // This implements a low pass filter to eliminate spike for ADC readings

  SendN2kEngine();
  CheckConnections();
  NMEA2000.ParseMessages();

  int SourceAddress = NMEA2000.GetN2kSource();
  if (SourceAddress != NodeAddress) { // Save potentially changed Source Address to NVS memory
    NodeAddress = SourceAddress;      // Set new Node Address (to save only once)
    preferences.begin("nvs", false);
    preferences.putInt("LastNodeAddress", SourceAddress);
    preferences.end();
    Serial.printf("Address Change: New Address=%d\n", SourceAddress);
  }

  tN2kDataToNMEA0183.Update(&BoatData);

  // Dummy to empty input buffer to avoid board to stuck with e.g. NMEA Reader
  if ( Serial.available() ) {
    Serial.read();
  }

  // Alarm handling
  button.tick();

#if ENABLE_DEBUG_LOG == 2
  Serial.print("Voltage:" ); Serial.println(voltage);
  //Serial.print("Temperature: ");Serial.println(temp);
  Serial.println("");
#endif

  alarmstate = false;
  if (temp > HighTempAlarm || voltage < LowVoltageAlarm) {
    alarmstate = true;
  }
  if (alarmstate == true && acknowledge == false) {
    digitalWrite(buzzerPin, HIGH);
  } else {
    digitalWrite(buzzerPin, LOW);
  }

  if (wifiType == 0) {                                          // Check connection if working as client
    wifi_retry = 0;
    while (WiFi.status() != WL_CONNECTED && wifi_retry < 5 ) {  // Connection lost, 5 tries to reconnect
      wifi_retry++;
      Serial.println("WiFi not connected. Try to reconnect");
      WiFi.disconnect();
      WiFi.mode(WIFI_OFF);
      WiFi.mode(WIFI_STA);
      WiFi.begin(CL_ssid, CL_password);
      delay(100);
    }
    if (wifi_retry >= 5) {
      Serial.println("\nReboot");                                  // Did not work -> restart ESP32
      ESP.restart();
    }
  }
}

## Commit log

2019-07-23 Add files via upload
    Version 0.2, Fixing complete AIS message reead/write.
    [Wifi-Serial-AP-AIS-CAN.ino]
2019-08-03 Add files via upload
    Verion 0.4. Added Rudder and water Temp plus TWD/TWS. Web gauge for fridge temp.
2019-08-11 Update Wifi-Serial-AP-AIS-CAN.ino
    Typos corrected.
    [Wifi-Serial-AP-AIS-CAN.ino]
2019-12-11 Added CAN pin definition.
2020-01-09 KiCad schematics
2020-01-09 Added KiCad schematics
2020-03-03 Corrected GND connection.
2020-07-23 Changes priority for GetTemperature task (core 0) to 0 to avoid delays fo task 1 (loop() task).
    [Wifi-Serial-AP-AIS-CAN.ino]
2020-07-23 Moved to current JSON library version (6.x.x.)
2020-07-24 Fixed AP setting problem
    [Wifi-Serial-AP-AIS-CAN.ino]
2020-08-04 Changed ESP32_CAN_TX_PIN from 2 to 5!
2020-11-01 Added KiCAD files
    [ESP32WifiAisTempVolt2.kicad_pcb, ESP32WifiAisTempVolt2.sch]
2020-11-06 Version 1.1
    [ESP32WifiAisTempVolt2.kicad_pcb, ESP32WifiAisTempVolt2.sch]
2022-02-05 Use new ESP32-API function name "esp_efuse_mac_get_default(chipid);"
